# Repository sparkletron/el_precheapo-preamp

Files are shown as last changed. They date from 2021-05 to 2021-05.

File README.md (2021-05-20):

# EL PRECHEAPO PREAMP

---
    AUTHOR: John Convertino   
    
    DATE: 2021.01.04   
    
    DETAILS: Cheap preamplifier   
---

### DIRECTORY
#### models
3D models
* back_panel.stl        - Back panel for preamplifier
* front_panel.stl       - Front panel for preamplifier
* side.stl              - Right/Left side for preamplifier
* top.stl               - Top for preamplifier
* bot.stl               - Bot for preamplifier
* el_precheapo.FCStd    - FreeCAD model of circuit board.
* el_precheapo.step     - FreeCAD model of circuit board in STEP format.

#### schematic
KiCad Schematic and PCBS
* el_precheapo.pro - Main KiCAD project file

#### docs
Articles and datasheets used for the project.
* jrc4556.pdf - Opamp datasheet

#### sim
Simulation and Spec Write Ups
* N/A

### PARTS LIST
* BACK PANEL... 1
* FRONT PANEL... 1
* SIDE... 2
* TOP... 1
* BOTTOM... 1
* PCB... 1
* SCHEMATIC PARTS LIST: Reference, Quantity, Value, Footprint, Datasheet
    * C1 C2 ,2,"1000uF","Capacitor_THT:CP_Radial_D12.5mm_P5.00mm","~"
    * C10 C9 C20 C19 ,4,"22pf","Capacitor_THT:C_Disc_D5.0mm_W2.5mm_P5.00mm","~"
    * C11 C14 ,2,"0.1UF","Capacitor_THT:C_Disc_D4.7mm_W2.5mm_P5.00mm","~"
    * C3 C4 ,2,"47uF","Capacitor_THT:CP_Radial_D8.0mm_P3.80mm","~"
    * C5 C6 C22 C21 ,4,"1UF","Capacitor_THT:C_Rect_L16.5mm_W7.0mm_P15.00mm_MKT","~"
    * C7 C8 C17 C18 C12 C13 C15 C16 ,8,"10UF","Capacitor_THT:CP_Radial_D8.0mm_P3.80mm","~"
    * D1 ,1,"D_Bridge_+AA-","Diode_THT:Diode_Bridge_15.1x15.1x6.3mm_P10.9mm","~"
    * F1 ,1,"0.5 AMP","Connector_Molex:Molex_KK-396_A-41791-0002_1x02_P3.96mm_Vertical","~"
    * F2 F3 ,2,"0.1 AMP","Connector_PinHeader_2.54mm:PinHeader_1x02_P2.54mm_Vertical","~"
    * H1 H2 H3 H4 ,4,"MountingHole","MountingHole:MountingHole_3mm_Pad","~"
    * J1 J2 ,2,"Conn_01x03","Connector_Molex:Molex_KK-254_AE-6410-03A_1x03_P2.54mm_Vertical","~"
    * J3 ,1,"Conn_01x02","Connector_Molex:Molex_KK-396_A-41791-0002_1x02_P3.96mm_Vertical","~"
    * R16 R15 ,2,"15K","Resistor_THT:R_Axial_DIN0207_L6.3mm_D2.5mm_P10.16mm_Horizontal","~"
    * R17 R18 ,2,"100K","Resistor_THT:R_Axial_DIN0207_L6.3mm_D2.5mm_P10.16mm_Horizontal","~"
    * R19 R20 ,2,"100","Resistor_THT:R_Axial_DIN0207_L6.3mm_D2.5mm_P10.16mm_Horizontal","~"
    * R2 R1 ,2,"1M","Resistor_THT:R_Axial_DIN0207_L6.3mm_D2.5mm_P10.16mm_Horizontal","~"
    * R3 R4 R12 R11 R13 R14 ,6,"10K","Resistor_THT:R_Axial_DIN0207_L6.3mm_D2.5mm_P10.16mm_Horizontal","~"
    * R6 R5 ,2,"22K","Resistor_THT:R_Axial_DIN0207_L6.3mm_D2.5mm_P10.16mm_Horizontal","~"
    * R8 R7 ,2,"150","Resistor_THT:R_Axial_DIN0207_L6.3mm_D2.5mm_P10.16mm_Horizontal","~"
    * R9 R10 ,2,"1K5","Resistor_THT:R_Axial_DIN0207_L6.3mm_D2.5mm_P10.16mm_Horizontal","~"
    * RV2 RV1 RV4 RV3 ,4,"R_POT","Connector_Molex:Molex_KK-254_AE-6410-03A_1x03_P2.54mm_Vertical","~"
    * SW1 ,1,"SW_SPST","Connector_Molex:Molex_KK-396_A-41791-0002_1x02_P3.96mm_Vertical","~"
    * T1 ,1,"Transformer_1P_SS","Connector_Molex:Molex_KK-396_A-41791-0005_1x05_P3.96mm_Vertical","~"
    * U1 ,1,"L7809","Package_TO_SOT_THT:TO-220-3_Vertical",
    * U2 ,1,"L7909","Package_TO_SOT_THT:TO-220-3_Vertical",
    * U3 U4 ,2,"NE5532","Package_DIP:DIP-8_W7.62mm_LongPads","http://www.ti.com/lit/ds/symlink/ne5532.pdf"

### BUILD HELP
* 3D print all parts with ABS at 101% to deal with shrinkage. Otherwise, good luck! I used parts I had around for the pots. Pulled from some 1970's stereo. No idea if you can find something that matches the case exactly.
* Balance pot is 5k
* Volume pot is 50k
* The pots can be changed as long as they have a 10x ratio. Also alter the resistors to countour the pots steps to your liking.

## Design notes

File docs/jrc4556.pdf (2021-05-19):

www.DataSheet4U.com www.datasheet4u.com | www.DataSheet4U.com

# NJM4558/4559

# MEMO

[CAUTION]
The specifications on this databook are only given for information , without any guarantee as regards either mistakes or omissions. The application circuits in this databook are described only to show representative usages of the product and not intended for the guarantee or permission of any right including the industrial rights.

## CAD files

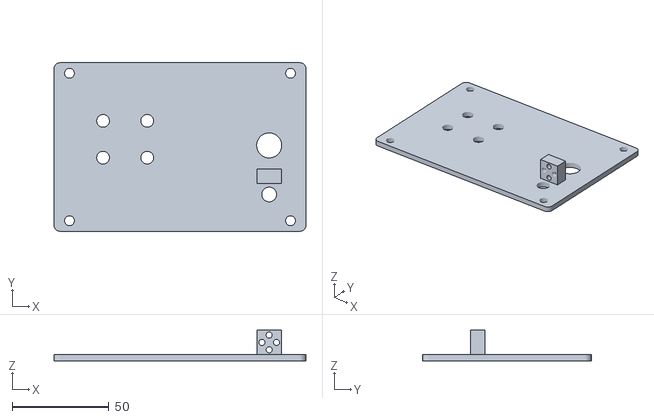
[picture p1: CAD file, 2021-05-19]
models/back_panel.stl
130.4 x 87.2 x 15.9

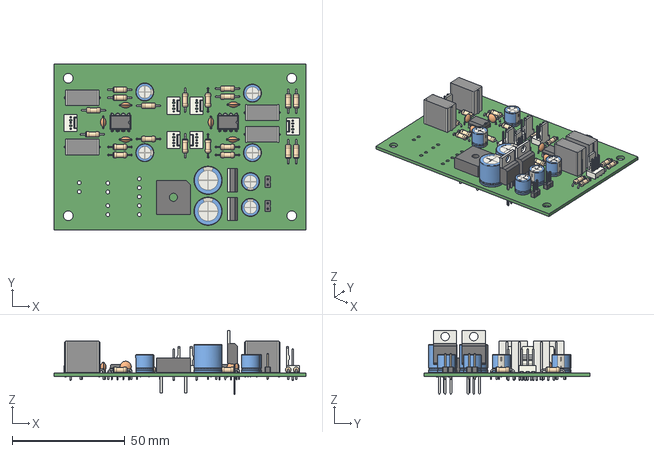
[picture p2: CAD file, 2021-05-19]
schematic/el_precheapo.step
111.8 x 73.7 x 28.5 mm

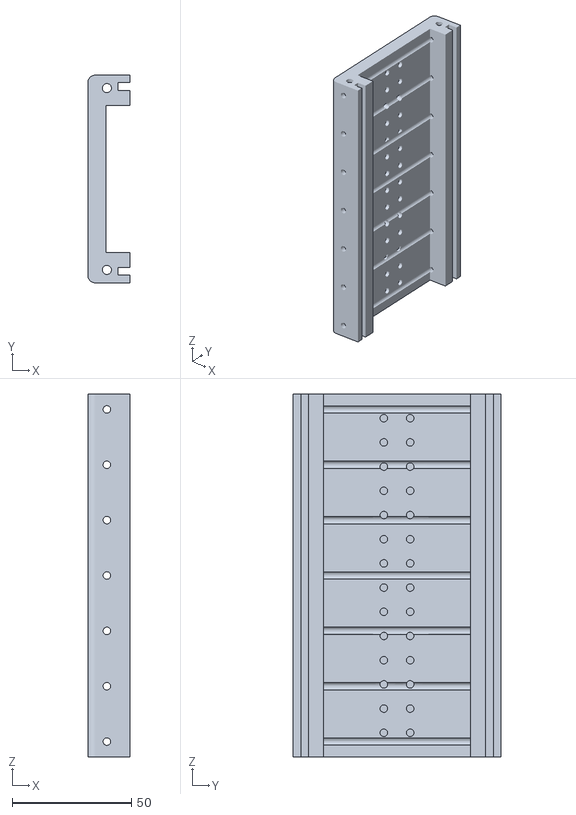
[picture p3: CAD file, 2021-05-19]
models/side.stl
17.8 x 87.2 x 152.4

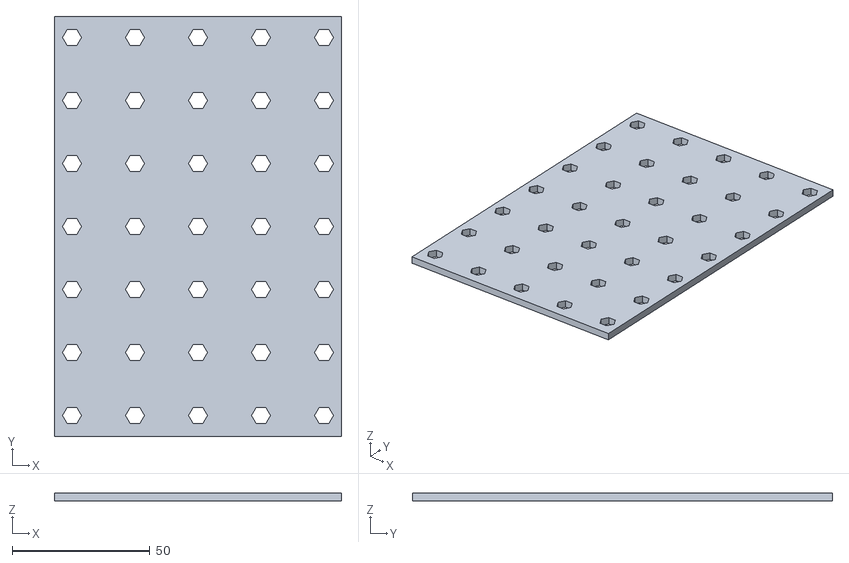
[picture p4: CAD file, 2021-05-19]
models/top.stl
104.1 x 152.4 x 3.05

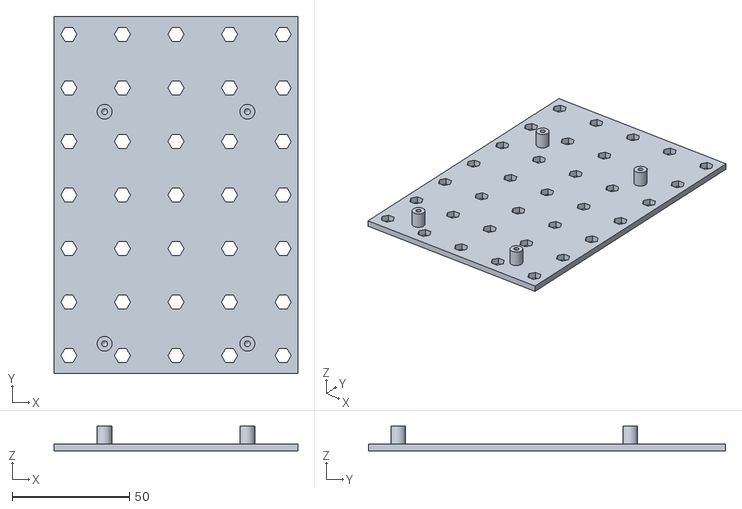
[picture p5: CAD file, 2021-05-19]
models/bot.stl
104.1 x 152.4 x 10.7

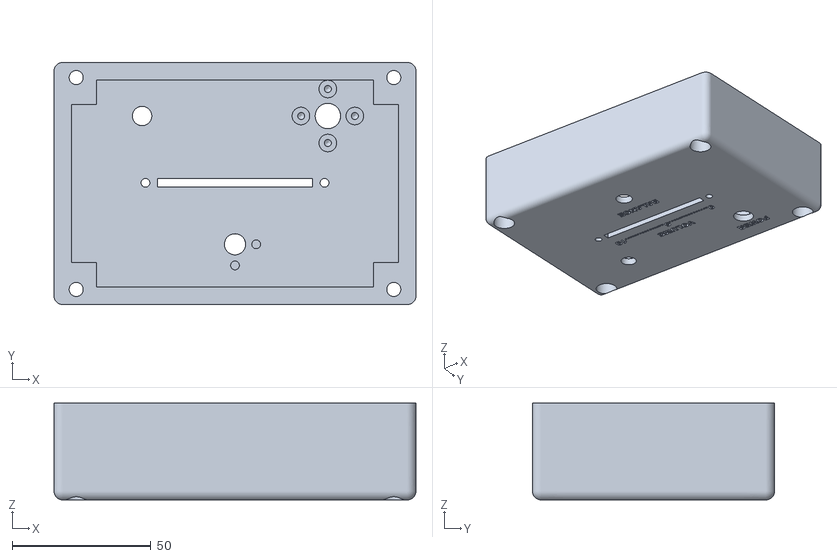
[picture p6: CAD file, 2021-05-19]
models/front_panel.stl
130.4 x 87.2 x 34.9

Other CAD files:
models/el_precheapo.FCStd

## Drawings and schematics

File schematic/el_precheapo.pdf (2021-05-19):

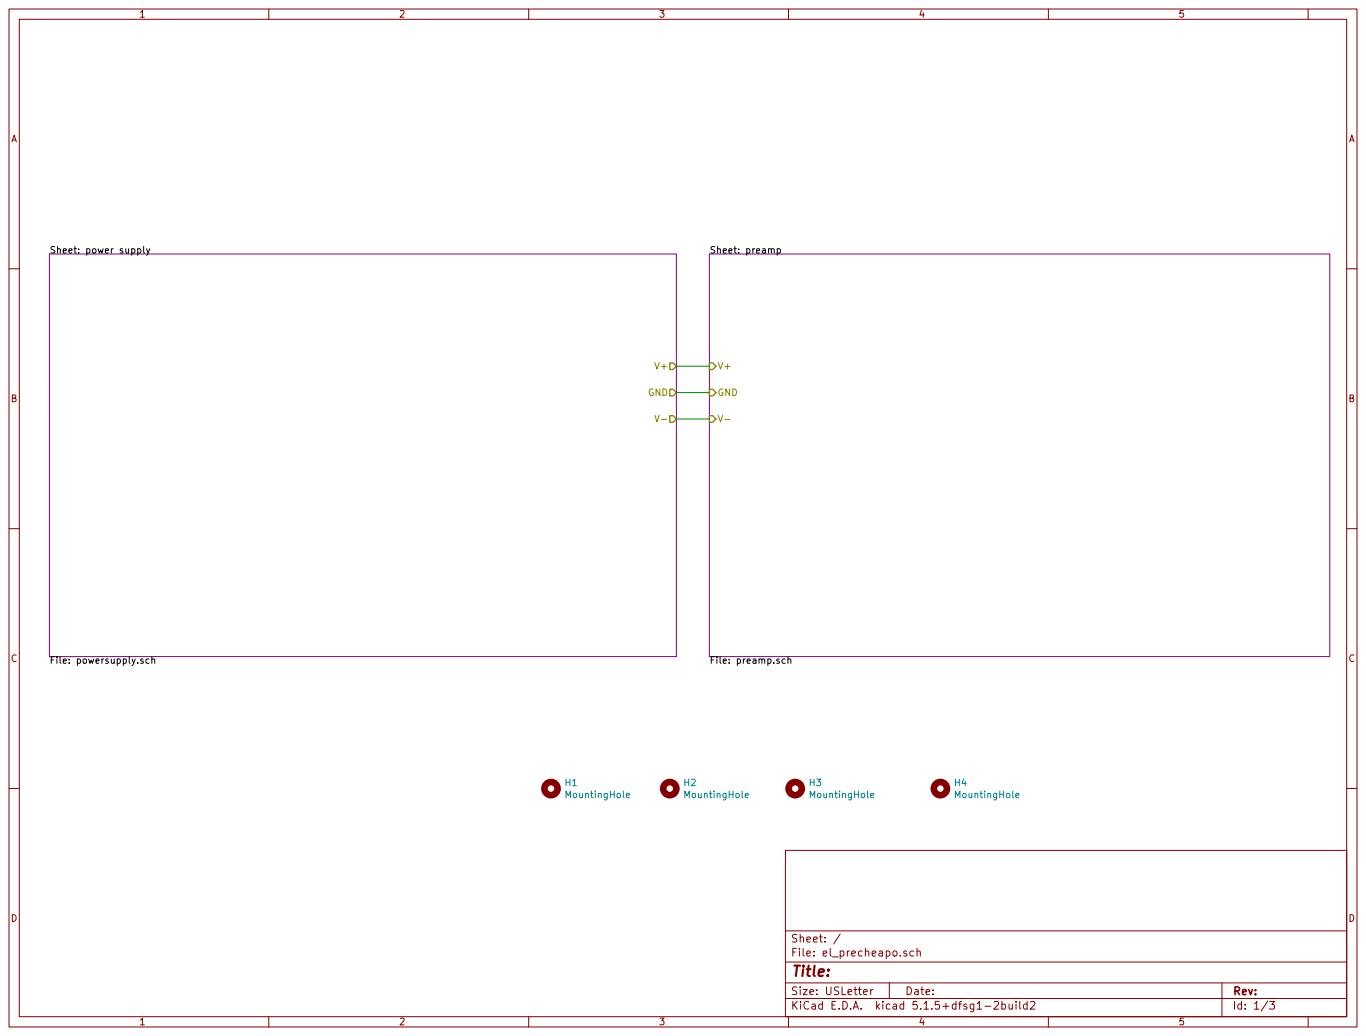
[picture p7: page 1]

File: preamp.sch V+V- GND

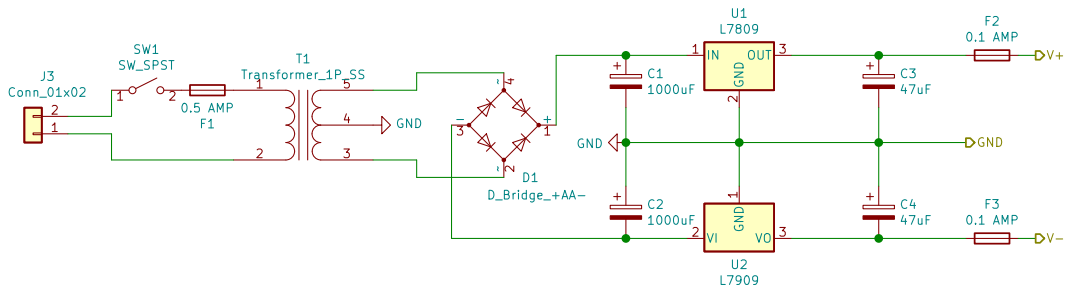
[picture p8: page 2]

2 OUT 3 U1
Sheet: /power supply/ GND

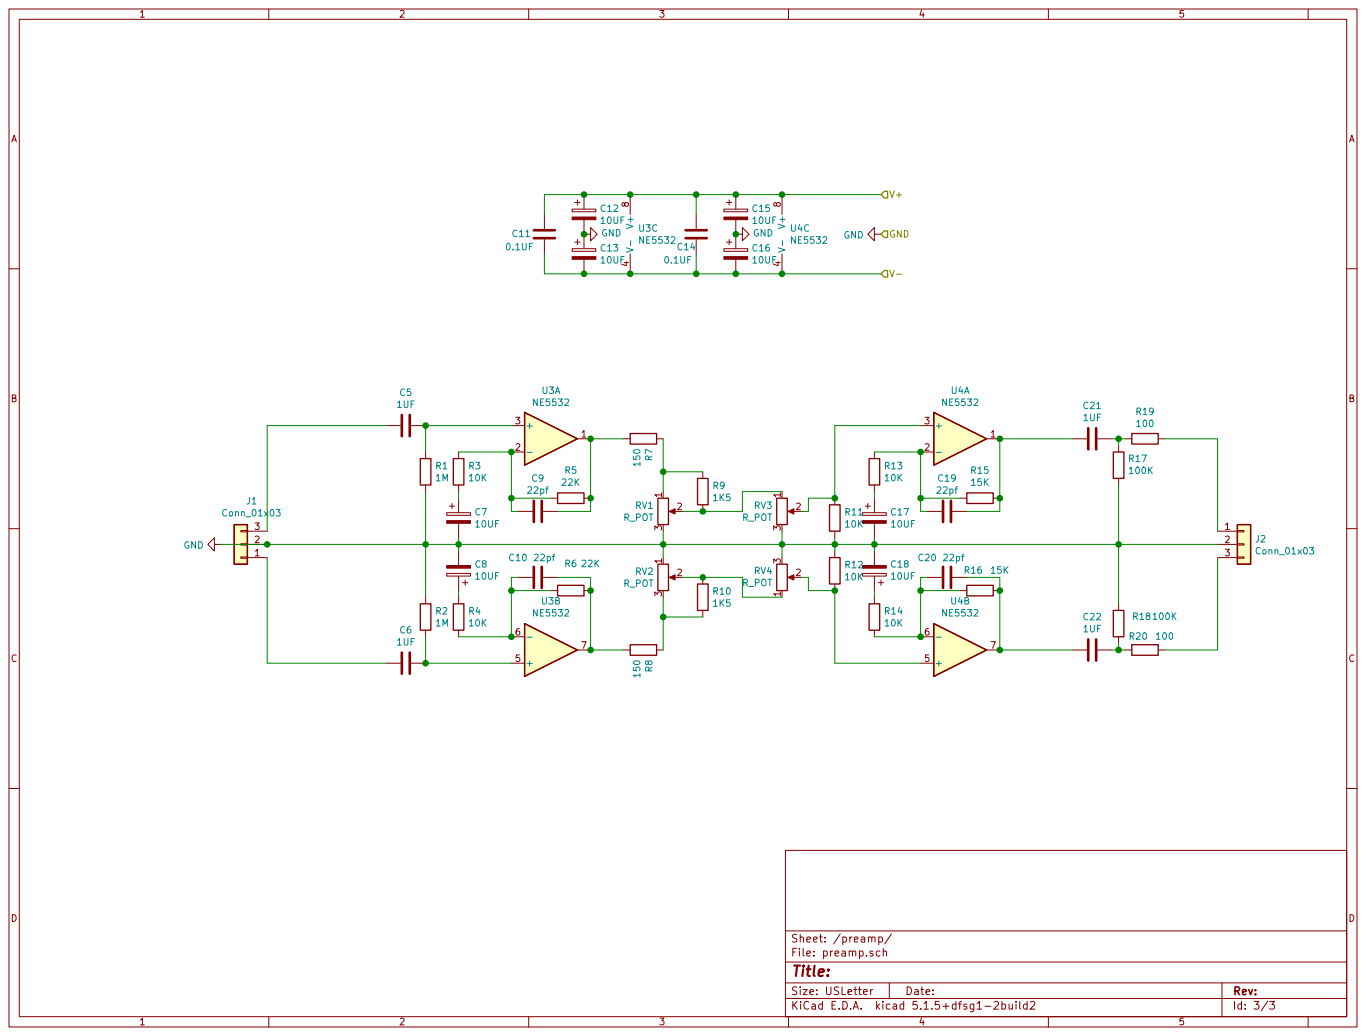
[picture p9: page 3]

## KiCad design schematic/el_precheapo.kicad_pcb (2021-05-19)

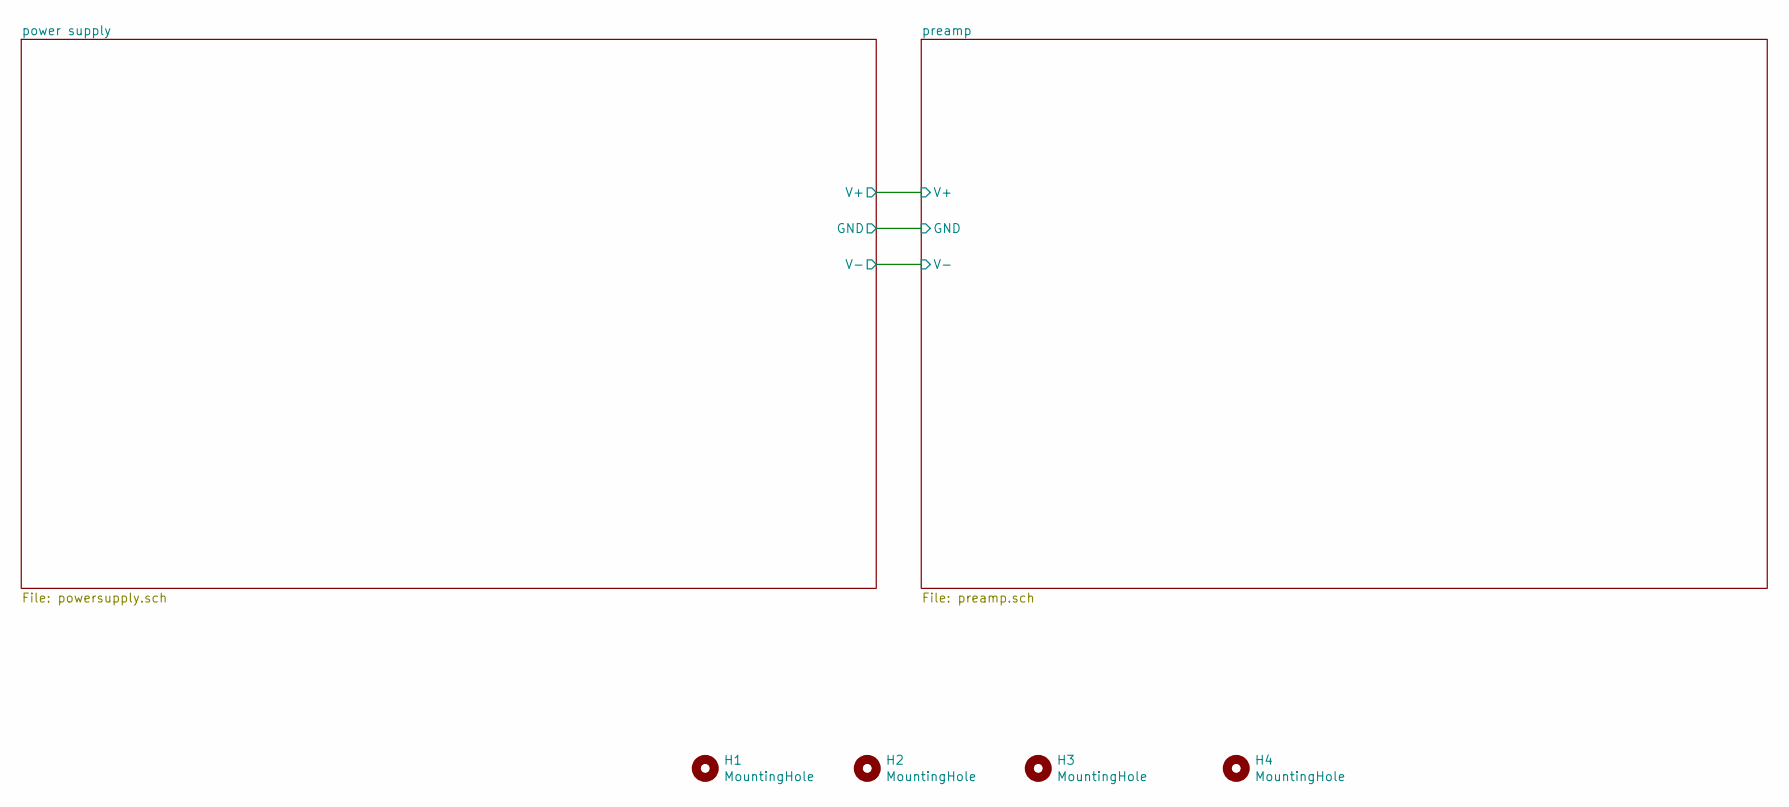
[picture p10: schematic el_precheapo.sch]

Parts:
H1, H2, H3, H4: MountingHole; MountingHole_3mm_Pad

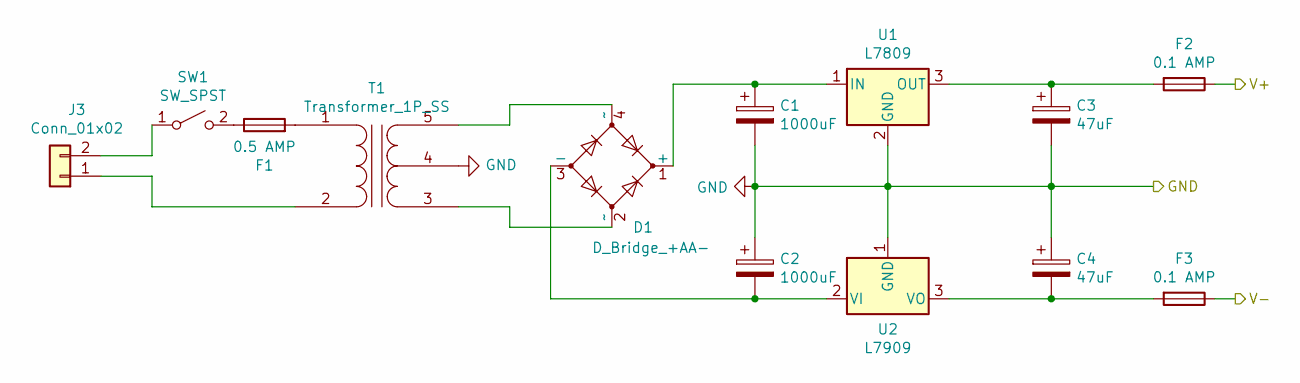
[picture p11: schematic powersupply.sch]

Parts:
C1, C2: 1000uF; CP_Radial_D12.5mm_P5.00mm
C3, C4: 47uF; CP_Radial_D8.0mm_P3.80mm
D1: D_Bridge_+AA-; Diode_Bridge_15.1x15.1x6.3mm_P10.9mm
F1: 0.5 AMP; Molex_KK-396_A-41791-0002_1x02_P3.96mm_Vertical
F2, F3: 0.1 AMP; PinHeader_1x02_P2.54mm_Vertical
J3: Conn_01x02; Molex_KK-396_A-41791-0002_1x02_P3.96mm_Vertical
SW1: SW_SPST; Molex_KK-396_A-41791-0002_1x02_P3.96mm_Vertical
T1: Transformer_1P_SS; Molex_KK-396_A-41791-0005_1x05_P3.96mm_Vertical
U1: L7809; TO-220-3_Vertical
U2: L7909; TO-220-3_Vertical

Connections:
/power supply/V+: F2.1; also elsewhere on the board
/power supply/V-: F3.1; also elsewhere on the board
GND: C1.2, C2.1, C3.2, C4.1, T1.4 (SC), U1.2 (GND), U2.1 (GND); also elsewhere on the board
unnamed: C1.1, D1.1 (+), U1.1 (IN)
unnamed: C2.2, D1.3 (-), U2.2 (VI)
unnamed: C3.1, F2.2, U1.3 (OUT)
unnamed: C4.2, F3.2, U2.3 (VO)
unnamed: D1.2 (~~), T1.3 (SA)
unnamed: D1.4 (~~), T1.5 (SB)
unnamed: F1.1, SW1.2 (B)
unnamed: F1.2, T1.1 (AA)
unnamed: J3.1, T1.2 (AB)
unnamed: J3.2, SW1.1 (A)

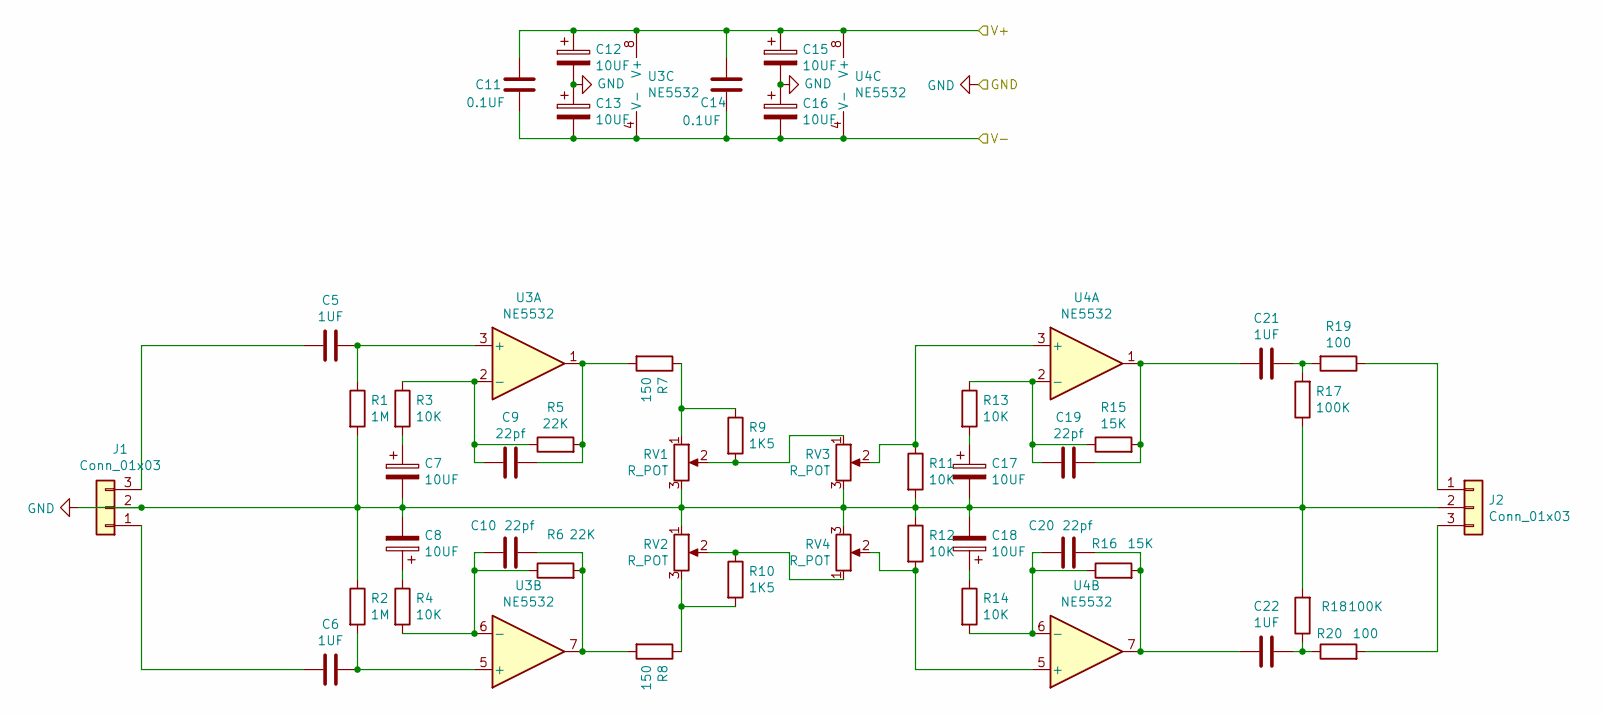
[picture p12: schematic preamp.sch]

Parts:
C5, C6, C21, C22: 1UF; C_Rect_L16.5mm_W7.0mm_P15.00mm_MKT
C7, C8, C12, C13, C15, C16, C17, C18: 10UF; CP_Radial_D8.0mm_P3.80mm
C9, C10, C19, C20: 22pf; C_Disc_D5.0mm_W2.5mm_P5.00mm
C11, C14: 0.1UF; C_Disc_D4.7mm_W2.5mm_P5.00mm
J1, J2: Conn_01x03; Molex_KK-254_AE-6410-03A_1x03_P2.54mm_Vertical
R1, R2: 1M; R_Axial_DIN0207_L6.3mm_D2.5mm_P10.16mm_Horizontal
R3, R4, R11, R12, R13, R14: 10K; R_Axial_DIN0207_L6.3mm_D2.5mm_P10.16mm_Horizontal
R5, R6: 22K; R_Axial_DIN0207_L6.3mm_D2.5mm_P10.16mm_Horizontal
R7, R8: 150; R_Axial_DIN0207_L6.3mm_D2.5mm_P10.16mm_Horizontal
R9, R10: 1K5; R_Axial_DIN0207_L6.3mm_D2.5mm_P10.16mm_Horizontal
R15, R16: 15K; R_Axial_DIN0207_L6.3mm_D2.5mm_P10.16mm_Horizontal
R17, R18: 100K; R_Axial_DIN0207_L6.3mm_D2.5mm_P10.16mm_Horizontal
R19, R20: 100; R_Axial_DIN0207_L6.3mm_D2.5mm_P10.16mm_Horizontal
RV1, RV2, RV3, RV4: R_POT; Molex_KK-254_AE-6410-03A_1x03_P2.54mm_Vertical
U3, U4: NE5532; DIP-8_W7.62mm_LongPads

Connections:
/power supply/V+: C11.2, C12.1, C14.2, C15.1, U3.8 (V+), U4.8 (V+); also elsewhere on the board
/power supply/V-: C11.1, C13.2, C14.1, C16.2, U3.4 (V-), U4.4 (V-); also elsewhere on the board
GND: C7.2, C8.2, C12.2, C13.1, C15.2, C16.1, C17.2, C18.2, J1.2, J2.2, R1.2, R2.1, R11.2, R12.1, R17.1, R18.2, RV1.3, RV2.1, RV3.3, RV4.3; also elsewhere on the board
unnamed: C5.1, R1.1, U3.3 (+)
unnamed: C5.2, J1.3
unnamed: C6.1, R2.2, U3.5 (+)
unnamed: C6.2, J1.1
unnamed: C7.1, R3.2
unnamed: C8.1, R4.1
unnamed: C9.1, R5.2, R7.2, U3.1
unnamed: C9.2, R3.1, R5.1, U3.2 (-)
unnamed: C10.1, R6.2, R8.2, U3.7
unnamed: C10.2, R4.2, R6.1, U3.6 (-)
unnamed: C17.1, R13.2
unnamed: C18.1, R14.1
unnamed: C19.1, C21.2, R15.2, U4.1
unnamed: C19.2, R13.1, R15.1, U4.2 (-)
unnamed: C20.1, C22.2, R16.2, U4.7
unnamed: C20.2, R14.2, R16.1, U4.6 (-)
unnamed: C21.1, R17.2, R19.2
unnamed: C22.1, R18.1, R20.1
unnamed: J2.1, R19.1
unnamed: J2.3, R20.2
unnamed: R7.1, R9.1, RV1.1
unnamed: R9.2, RV1.2, RV3.1
unnamed: R10.1, RV2.2, RV4.1
unnamed: R8.1, R10.2, RV2.3
unnamed: R11.1, RV3.2, U4.3 (+)
unnamed: R12.2, RV4.2, U4.5 (+)

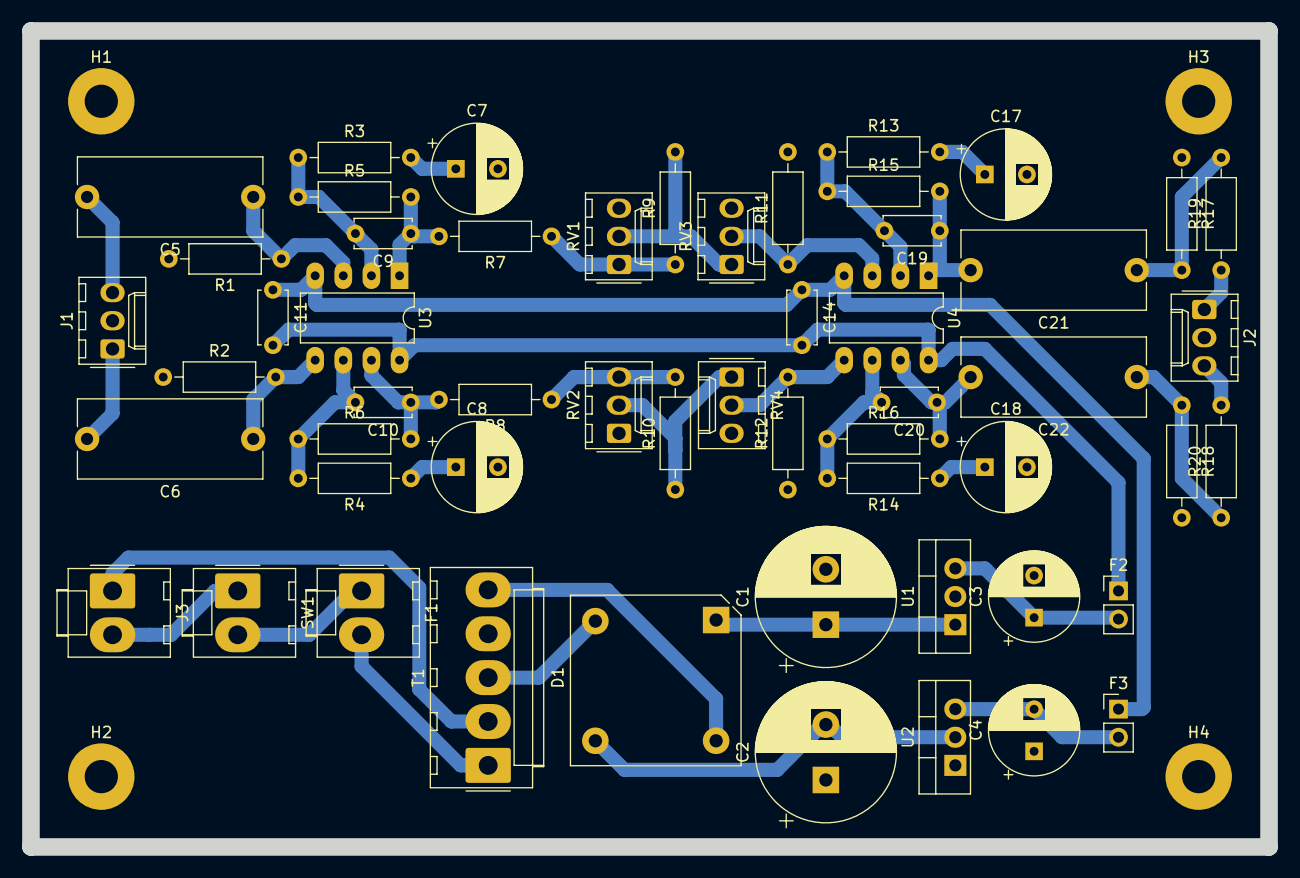
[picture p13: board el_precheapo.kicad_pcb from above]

Board: 2 copper layers, 111.8 x 73.7 mm, 59 parts (0 on the bottom side), 39 nets.
